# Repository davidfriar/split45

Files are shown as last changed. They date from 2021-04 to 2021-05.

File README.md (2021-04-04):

# The Split Forty Five

A small mechanical keyboard for those who cannot decide if they are ancient or modern.

* "Traditional" row-staggered layout
* Split for better ergonomics
* Based on the Nice!Nano controller for very low power consumption
* Uses Bluetooth Low Energy (BLE) both to connect each half and to connect to the computer

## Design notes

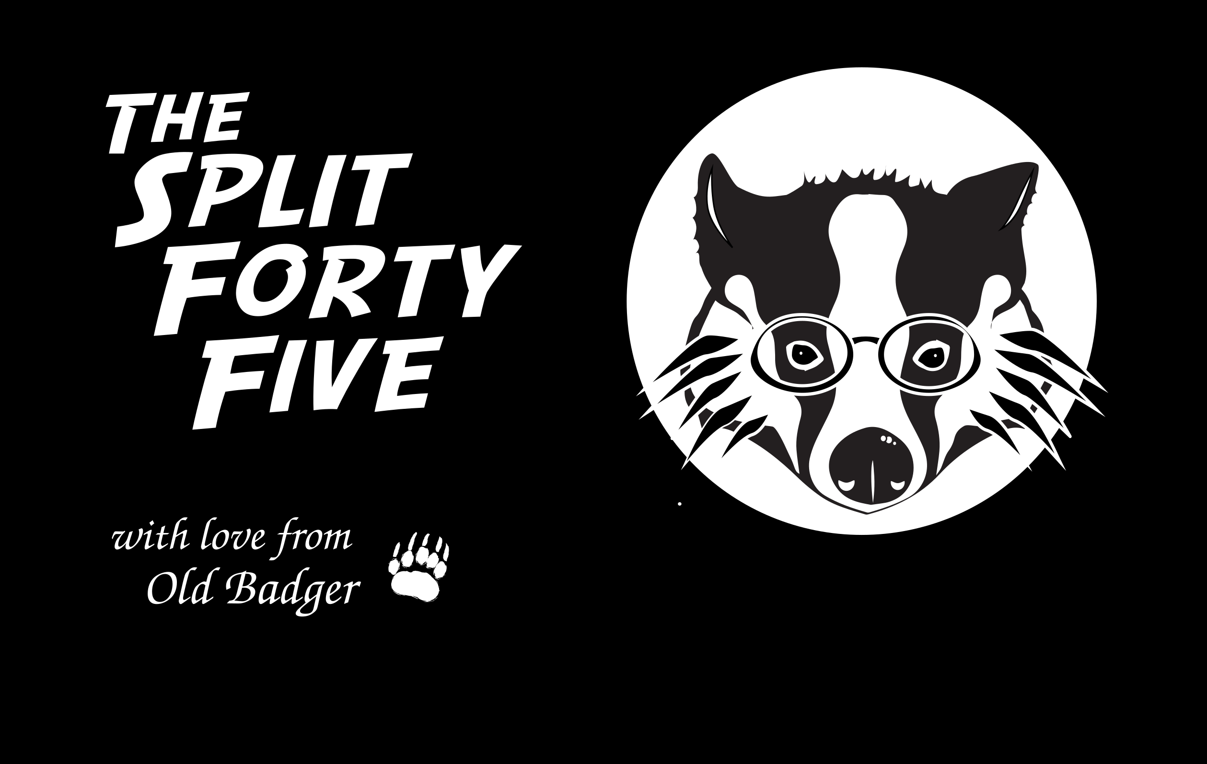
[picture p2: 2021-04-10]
art/bottom.png

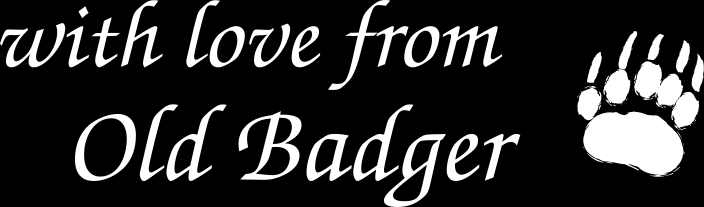
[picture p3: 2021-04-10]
art/withlove.png

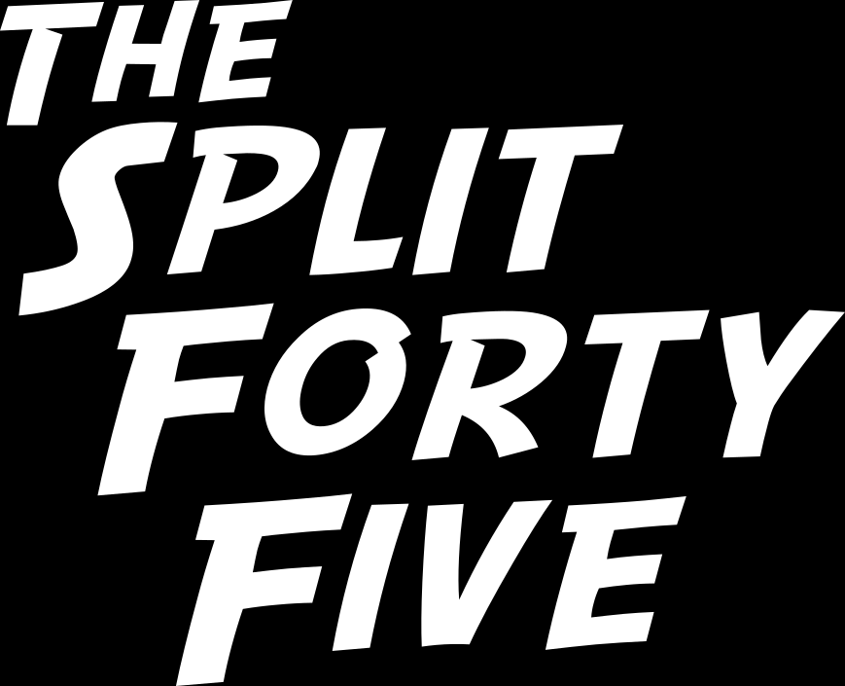
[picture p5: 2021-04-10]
art/split45.png

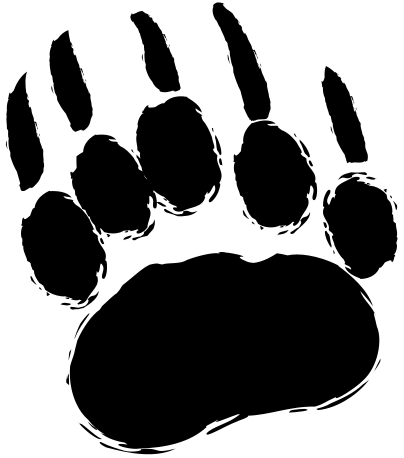
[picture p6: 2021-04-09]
art/rightpaw.png

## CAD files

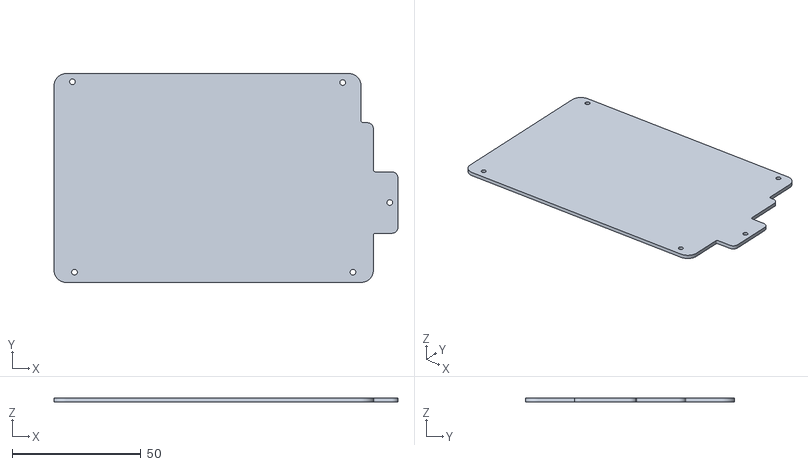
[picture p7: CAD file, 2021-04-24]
case/pcbmodels/split45leftbase.stl
133.4 x 81.0 x 1.60

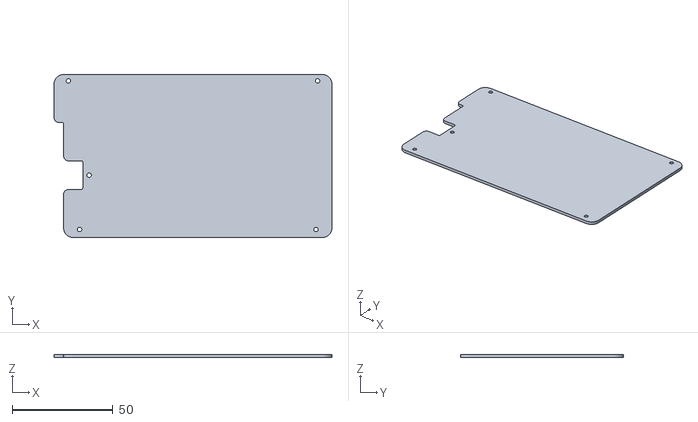
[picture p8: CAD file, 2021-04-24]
case/pcbmodels/split45rightbase.stl
138.1 x 81.0 x 1.60

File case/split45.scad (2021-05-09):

include <BOSL/constants.scad>
use <BOSL/transforms.scad>
include <pcbmodels/holes.scad>
include <pcbmodels/dimensions.scad>
include <pcbmodels/corners.scad>
$fn = 360;
$fs = 1;

show_left=true;
show_right=true;
show_base=true;
show_pcb=true;

wall_thickness=8;
interior_corner_radius=3;
min_height=5;
tilt=6; // [0:0.5:15]
tent=8; // [0:45]
socket_height=4.95;
hole_diameter=3.2;
hole_depth=4.25;
clearance_hole_depth=2;
clearance_hole_offset=1.5;
switch_clearance_hole_offset=11;
stab_clearance_hole_offset=2;
nano_length=33.3;
nano_width=18.1;
nano_thickness=1.6;
nano_clearance=1;
usb_socket_length=8.9;
usb_plug_width=8.9;
usb_plug_height=3.2;
usb_plug_length=8.54;
usb_sheath_offset=2;
usb_sheath_width=usb_plug_width+2*usb_sheath_offset;
usb_sheath_height=usb_plug_height+2*usb_sheath_offset;
usb_sheath_length=30;

/* all(); */
pack();
/* clearance_holes(true); */
/* stab_clearance_holes(true); */
/* switch_clearance_holes(true); */
/* nice_nano_cutout(); */
/* usb_cutout(); */

/* name(); */
/*
to do:


all function
explode
bottom holes
top holes
pcb clearance
right interior
name
pcb / usb cutout
check weird alignment error with nano holes
battery holder
info panel (including clearance height for nano)

pack for printing
*/

module pack() {
  right(5) xrot(180){
    body(true);
    up(40) xrot(180) back(dimensions(false).y) body(false);
  }
}


module all(){
  if(show_left) {
    base(true) body(true) pcb(true) ;
  }
  if(show_right) {
    if(show_left) {
      xmove(left_size.x *1.25)
        base(false) body(false) pcb(false) ;
    }
    else{
      base(false) body(false) pcb(false) ;
    }
  }
}

module body(l=true){
  color("grey")
    difference(){
      body3d(l);
      down(0.1) scale([1,1, 1.1]) body3d(l, interior=true);
      bottom_holes(l);
      tilt_and_tent(l) top_holes(l);
      tilt_and_tent(l) switch_clearance_holes(l);
      tilt_and_tent(l) stab_clearance_holes(l);
      tilt_and_tent(l) name(l);
      align_nano(l, false) down(0.1) scale([1,1, 1.1]) nice_nano_cutout(l);
      tilt_and_tent(l) align_nano(l) translate([-(nano_clearance+1.5), nano_width/2, usb_plug_height/2]) usb_cutout();
    }

  tilt_and_tent(l) children();
}

module body3d(l=true, interior=false){
  for(part = corners(l)) {
    body_part(part, l, interior);
  }
  for(f=fillets(l)){
    fillet(f, l, interior);
  }

}

module body_part(corners, l=true, interior=false) {
  hull() {
    to3d() body_part_2d(corners, l, interior);
    tilt_and_tent(l) to3d() body_part_2d(corners, l, interior);
  }
}




module body_part_2d(corners, l=true, interior=false) {
  offset_interior(interior){
    hull(){
      for(corner = corners) {
        translate([corner.x, corner.y, 0]) circle(corner.z);
      }
    }
  }
}

module offset_interior(interior=false){
  if(interior){
    offset(r=interior_corner_radius)offset(r=-(wall_thickness+interior_corner_radius))  children();
  }
  else {
    children();
  }
}

module to3d(){
  for(i = [0:$children-1]){
    linear_extrude(height=0.0001) children(i);
  }
}

module fillet(f, l=true, interior=false){
  difference(){
    hull(){
      to3d() fillet_2d(f, interior);
      tilt_and_tent(l) to3d() fillet_2d(f, interior);
    }

    down(0.001) scale([1,1, 1.001]){
      hull(){
        to3d() fillet_mask_2d(f, interior);
        tilt_and_tent(l) to3d() fillet_mask_2d(f, interior);
      }
    }
  }
}

module fillet_2d(f, interior=false) {
  fillet_offset(f, interior) translate([f.x, f.y, 0]) flip(f[4], f[3]) square(f.z);
}

module fillet_offset(f, interior){
  if(interior){
    translate([f[4]?-wall_thickness:wall_thickness, f[3]?-wall_thickness:wall_thickness, 0]) children();
  }
  else{
    children();
  }
}
module flip(x, y) {
  if(x){
    if(y) {
      xflip() yflip() children();
    }
    else {
      xflip() children();
    }
  }
  else{
    if(y){
      yflip() children();
    }
    else {
      children();
    }
  }
}

module fillet_mask_2d(f, interior) {
  fillet_offset(f, interior) translate([f.x, f.y, 0]) circle(f.z);
}

module bottom_holes(l=true){
  for(hole = base_holes(l)){
    translate([hole.x, hole.y, -1]) cylinder(d=hole_diameter, h=hole_depth+1);
  }
}


module top_holes(l=true){
  for(hole = holes(l) ){
    if (hole[3]=="T2"){
      translate([hole.x, hole.y, -hole_depth]) cylinder(d=hole_diameter, h=hole_depth+1);
    }
  }
}

module clearance_holes(l=true) {
  for(hole = holes(l)){
    if (hole[3]!="T2"){
      translate([hole.x, hole.y, -clearance_hole_depth]) cylinder(d=hole.z+clearance_hole_offset, h=clearance_hole_depth+1);

    }
  }
  for(hole = plated_holes(l)){
    translate([hole.x, hole.y, -clearance_hole_depth]) cylinder(d=hole.z+clearance_hole_offset, h=clearance_hole_depth+1);
  }

}

module switch_clearance_holes(l=true){
  for(hole=switch_holes(l)) {
    color("blue") translate([hole.x, hole.y, -clearance_hole_depth]) cylinder(d=hole.z+switch_clearance_hole_offset, h=clearance_hole_depth+1);
  }
}

module stab_clearance_holes(l=true){
  for(hole=stab_holes(l)) {
    color("red") translate([hole.x, hole.y, -clearance_hole_depth]) cylinder(d=hole.z+stab_clearance_hole_offset, h=clearance_hole_depth+1);
  }
}

module tilt_and_tent(l=true) {
  /* translate([0,0, min_height + (tan(tent)*dimensions(l).x * 0.5)+(tan(tilt)*dimensions(l).y * 0.5)]) */
  zmove(min_height)
    ymove(-dimensions(l).y) xmove(l?0:right_size.x) yrot(tent_angle(l)) xrot(tilt) xmove(l?0:-right_size.x) ymove(dimensions(l).y)
    children();
}

function dimensions(l) = l ? left_size : right_size ;

function base_holes(l) = l ? left_base_holes : right_base_holes ;

function holes(l) = l ? left_holes : right_holes ;

function plated_holes(l) = l ? left_plated_holes : right_plated_holes ;

function tent_angle(l) = l ? -tent : tent ;

function corners(l) = l ? left_corners : right_corners;

function fillets(l) = l ?  left_fillets : right_fillets ;

function switch_holes(l) = [ for( hole = holes(l)) if (hole[3] == "T4" && hole.y > -70) hole ];

function stab_holes(l) = [ for( hole = holes(l)) if (hole[3] == "T3" || (hole[3] == "T4" && hole.y < -70)) hole ];

module pcb(l=true){
  if(show_pcb){
    color("red")up(dimensions(l).z)  {
      if (l) {
        pcb_left();
      }
      else {
        pcb_right();
      }
    }
    //translate([0,0,-(1.6+socket_height)]) nice_nano();
    align_nano(l) nice_nano();
  }
}

module centered(l=true) {
  translate([-dimensions(l).x/2, dimensions(l).y/2, 0]) children();
}

module base(l=true){
  if(show_base){
    color("red")up(dimensions(l).z)  {
      if (l) {
        base_left();
      }
      else {
        base_right();
      }
    }
  }
  up(dimensions(l).z) children();
}

module pcb_left() {
  import("pcbmodels/split45left.stl");
}

module pcb_right() {
  import("pcbmodels/split45right.stl");
}

module base_left() {
  import("pcbmodels/split45leftbase.stl");
}

module base_right() {
  import("pcbmodels/split45rightbase.stl");
}

module nice_nano() {
  nano_socket_border = (nano_width - 2.54*7) / 2 ;
  color("dimgray") rounded_rect([nano_length, nano_width, nano_thickness], radius=1.5);
  translate([ 0, (nano_width - usb_socket_length)/2 , 0 ]) rotate([90,0,90]) usb_socket();
  for(i=[0:1]){
    translate([2.82,nano_socket_border+i*6*2.54,nano_thickness]) socket();
  }
}


module nice_nano_cutout(left=true){

  translate([-nano_clearance, -nano_clearance]) hull(){
    rounded_rect([nano_length + 2*nano_clearance, nano_width+2*nano_clearance, 0.001], 1.5);
    tilt_and_tent(left) rounded_rect([nano_length + 2*nano_clearance, nano_width+2*nano_clearance, 0.001], 1.5);
  }
}


module rounded_rect(size, radius=5){
  hull(){
    translate([radius, radius]) cylinder(h=size.z, r=radius);
    translate([size.x-radius, radius]) cylinder(h=size.z, r=radius);
    translate([radius, size.y-radius]) cylinder(h=size.z, r=radius);
    translate([size.x-radius, size.y-radius]) cylinder(h=size.z, r=radius);
  }
}


module usb_socket(){
  color("silver") rounded_rect([8.9, 3.2, 6.5],radius=1);
}

module usb_cutout(){
  translate([0, -usb_sheath_width/2, -usb_sheath_height/2]) zrot(90)xrot(90) {
    translate([usb_sheath_offset, usb_sheath_offset, 0]) rounded_rect([usb_plug_width, usb_plug_height, usb_plug_length],radius=1);
    translate([0,0, -usb_sheath_length]) rounded_rect([usb_sheath_width, usb_sheath_height, usb_sheath_length],radius=3);
  }


}

module socket() {
  difference(){
    color("black") cube([30.48, 2.54, socket_height]);
    for(i=[0:11]){
      translate([1.27+i*2.54, 1.27, -1 ]) cylinder(d=1.092,h=10);
    }
  }
}


module align_nano(l=true, align_z=true){
  offsetX = l ? 3.3715 : 102.712+33.3-1.27;
  offsetY = l ? -40: -21.747;    // to do: was expecting left offset to be 40.147 - where is this error coming from?
  offsetZ = align_z ? -(1.6+socket_height) : 0 ;
  rotZ = l ? 0 : 180;
  translate([offsetX,offsetY,offsetZ ]) zrot(rotZ) children();
}
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

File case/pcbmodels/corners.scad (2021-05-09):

left_corners = [
  [
    [4.7625, -4.7625, 4.7625 ],
    [114.3, -4.7625, 4.7625 ],
    [4.7625, -76.2, 4.7625 ],
    [114.3, -76.2, 4.7625 ],
  ],
  [
    [4.7625, -76.2, 4.7625 ],
    [119.062, -76.2, 4.7625 ],
    [121.444, -21.4312, 2.38125 ],
    [4.7625, -21.4312, 2.38125 ]
  ],
  [
    [130.969, -59.5312, 2.38125 ],
    [130.969, -40.4812, 2.38125 ],
    [4.7625, -59.5312, 2.38125 ],
    [4.7625, -40.4812, 2.38125 ],
  ]
];



left_fillets = [
  [124.619, -62.7063, 0.79375, false , true],
  [124.619, -37.3062, 0.79375, true , true],
  [119.856, -18.2563, 0.79375, true , true]
];


right_corners = [
  [
    [133.35, -76.2, 4.7625 ],
    [133.35, -4.7625, 4.7625 ],
    [19.05005, -76.2, 4.7625 ],
    [19.05005, -4.7625, 4.7625 ],
  ],
  [
    [9.525, -76.2, 4.7625 ],
    [133.35, -76.2, 4.7625 ],
    [7.14375, -59.5312, 2.38125 ],
    [133.35, -59.5312, 2.38125 ],
  ],
  [
    [7.14375, -40.4812, 2.38125 ],
    [7.14375, -2.38125, 2.38125 ],
    [135.73125, -40.4812, 2.38125 ],
    [133.35, -4.7625, 4.7625 ],
  ],
  [
    [4.7625, -4.7625, 4.7625 ],
    [133.35, -4.7625, 4.7625 ],
    [2.38125, -21.4312, 2.38125 ],
    [133.35, -21.4312, 2.38125 ],
  ]
  ];

right_fillets = [
  [3.96875, -24.6062, 0.79375, false, false ],
  [13.4938, -43.6562, 0.79375, false, false ],
  [13.4938, -56.3562, 0.79375, true, false ],
];

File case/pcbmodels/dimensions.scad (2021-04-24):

left_size = [133.35, 80.9625, 1.6];
right_size = [138.113, 80.9625, 1.6];

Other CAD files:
case/pcbmodels/holes.scad

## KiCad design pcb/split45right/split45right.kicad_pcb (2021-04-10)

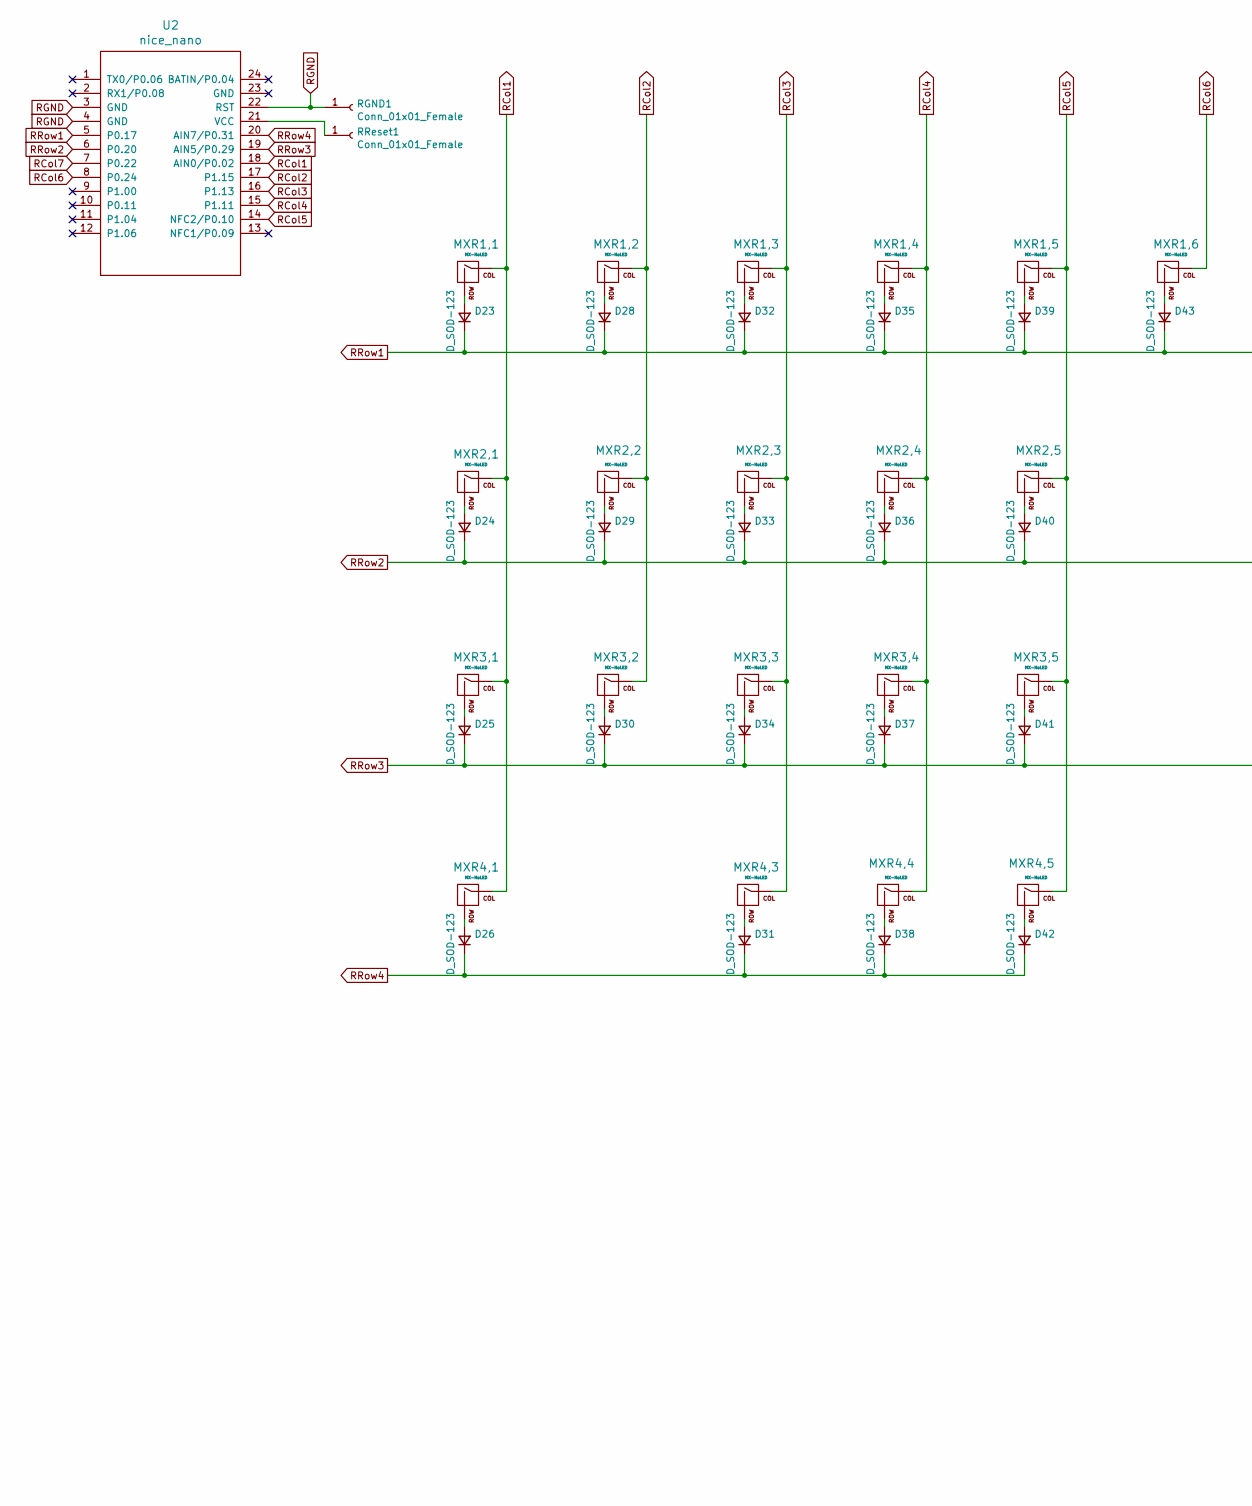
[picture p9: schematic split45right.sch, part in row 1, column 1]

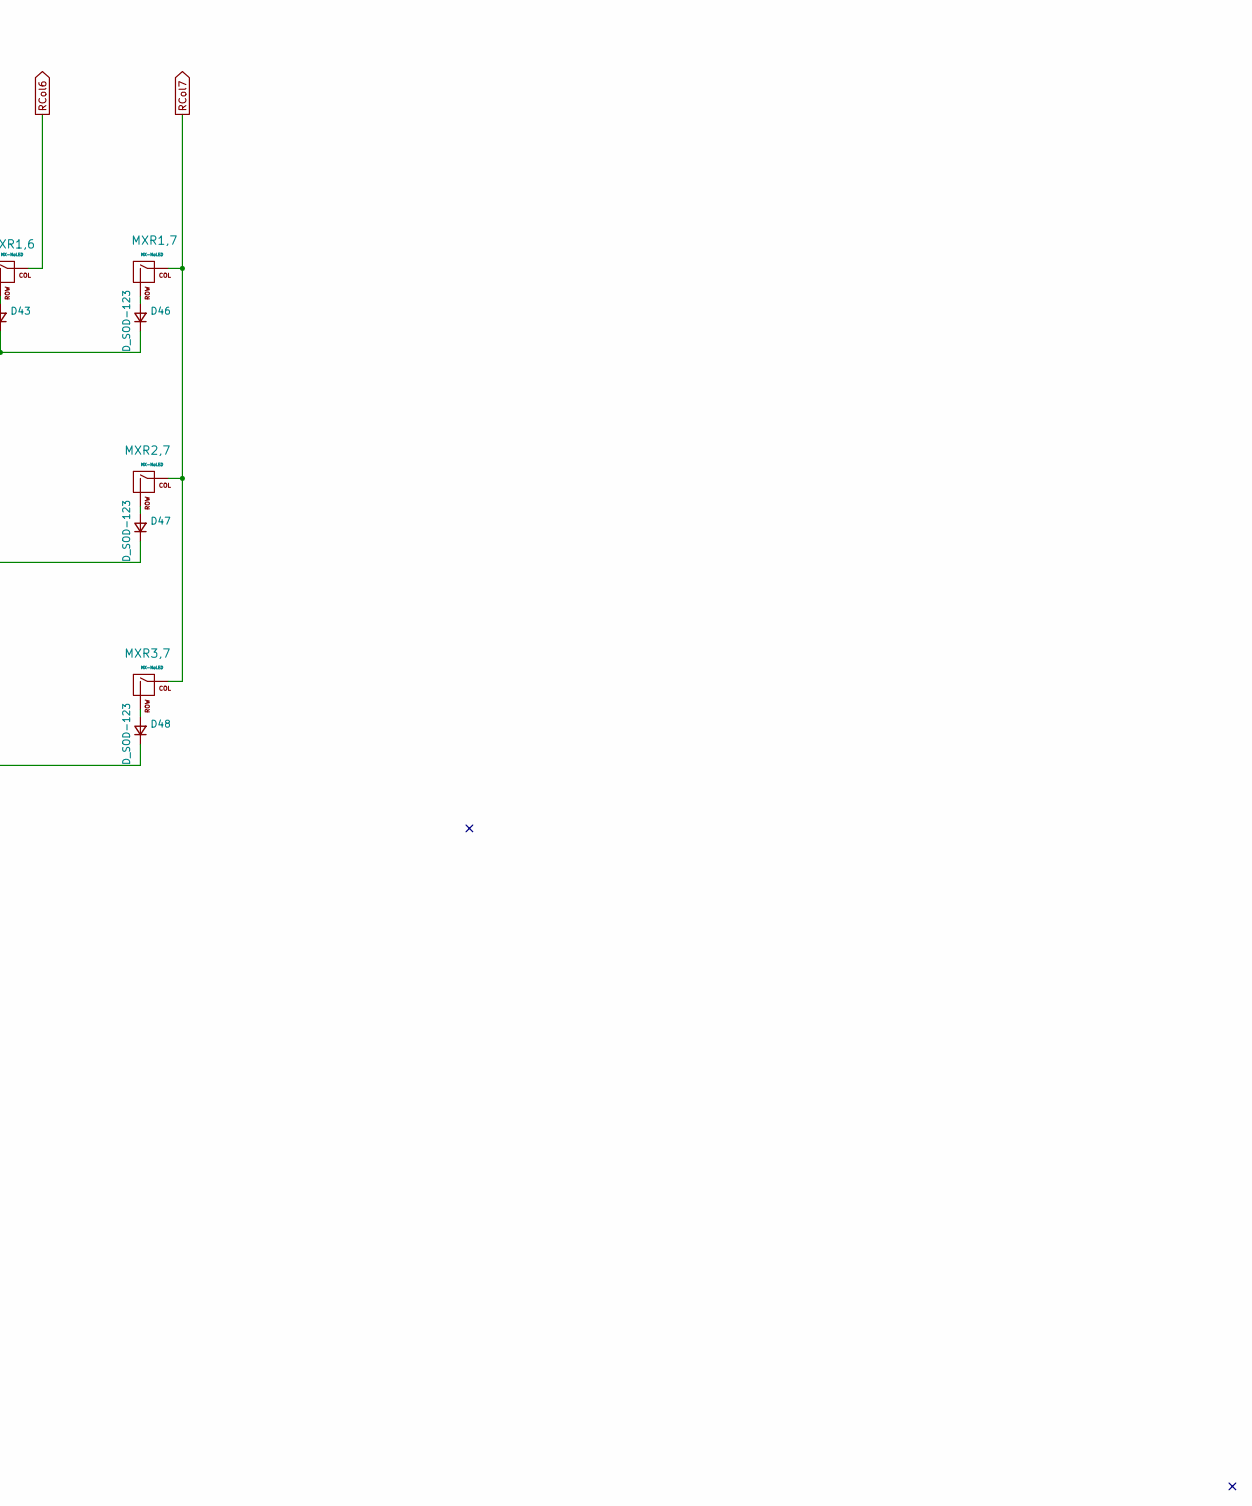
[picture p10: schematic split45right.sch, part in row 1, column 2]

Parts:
D23, D24, D25, D26, D28, D29, D30, D31, D32, D33, D34, D35, D36, D37, D38, D39, D40, D41, D42, D43, D46, D47, D48: D_SOD-123
MXR1,1, MXR1,2, MXR1,3, MXR1,4, MXR1,5, MXR1,6, MXR1,7, MXR2,1, MXR2,2, MXR2,3, MXR2,4, MXR2,5, MXR3,1, MXR3,2, MXR3,3, MXR3,4, MXR3,5, MXR4,3, MXR4,5: MX-NoLED; MXOnly-1U-NoLED
MXR2,7: MX-NoLED; MXOnly-1.75U-NoLED
MXR3,7, MXR4,4: MX-NoLED; MXOnly-1.25U-NoLED
MXR4,1: MX-NoLED; MXOnly-2.75U-NoLED
RGND1: Conn_01x01_Female; SolderWire-0.15sqmm_1x01_D0.5mm_OD1.5mm
RReset1: Conn_01x01_Female; SolderWire-0.15sqmm_1x01_D0.5mm_OD1.5mm
U2: nice_nano

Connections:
unnamed: D23.2 (A), MXR1,1.2 (ROW)
unnamed: D24.2 (A), MXR2,1.2 (ROW)
unnamed: D25.2 (A), MXR3,1.2 (ROW)
unnamed: D26.2 (A), MXR4,1.2 (ROW)
unnamed: D28.2 (A), MXR1,2.2 (ROW)
unnamed: D29.2 (A), MXR2,2.2 (ROW)
unnamed: D30.2 (A), MXR3,2.2 (ROW)
unnamed: D31.2 (A), MXR4,3.2 (ROW)
unnamed: D32.2 (A), MXR1,3.2 (ROW)
unnamed: D33.2 (A), MXR2,3.2 (ROW)
unnamed: D34.2 (A), MXR3,3.2 (ROW)
unnamed: D35.2 (A), MXR1,4.2 (ROW)
unnamed: D36.2 (A), MXR2,4.2 (ROW)
unnamed: D37.2 (A), MXR3,4.2 (ROW)
unnamed: D38.2 (A), MXR4,4.2 (ROW)
unnamed: D39.2 (A), MXR1,5.2 (ROW)
unnamed: D40.2 (A), MXR2,5.2 (ROW)
unnamed: D41.2 (A), MXR3,5.2 (ROW)
unnamed: D42.2 (A), MXR4,5.2 (ROW)
unnamed: D43.2 (A), MXR1,6.2 (ROW)
unnamed: D46.2 (A), MXR1,7.2 (ROW)
unnamed: D47.2 (A), MXR2,7.2 (ROW)
unnamed: D48.2 (A), MXR3,7.2 (ROW)
unnamed: RReset1.1, U2.21 (VCC)
RCol1: MXR1,1.1 (COL), MXR2,1.1 (COL), MXR3,1.1 (COL), MXR4,1.1 (COL), U2.18 (AIN0/P0.02)
RCol2: MXR1,2.1 (COL), MXR2,2.1 (COL), MXR3,2.1 (COL), U2.17 (P1.15)
RCol3: MXR1,3.1 (COL), MXR2,3.1 (COL), MXR3,3.1 (COL), MXR4,3.1 (COL), U2.16 (P1.13)
RCol4: MXR1,4.1 (COL), MXR2,4.1 (COL), MXR3,4.1 (COL), MXR4,4.1 (COL), U2.15 (P1.11)
RCol5: MXR1,5.1 (COL), MXR2,5.1 (COL), MXR3,5.1 (COL), MXR4,5.1 (COL), U2.14 (NFC2/P0.10)
RCol6: MXR1,6.1 (COL), U2.8 (P0.24)
RCol7: MXR1,7.1 (COL), MXR2,7.1 (COL), MXR3,7.1 (COL), U2.7 (P0.22)
RGND: RGND1.1, U2.3 (GND), U2.4 (GND), U2.22 (RST)
RRow1: D23.1 (K), D28.1 (K), D32.1 (K), D35.1 (K), D39.1 (K), D43.1 (K), D46.1 (K), U2.5 (P0.17)
RRow2: D24.1 (K), D29.1 (K), D33.1 (K), D36.1 (K), D40.1 (K), D47.1 (K), U2.6 (P0.20)
RRow3: D25.1 (K), D30.1 (K), D34.1 (K), D37.1 (K), D41.1 (K), D48.1 (K), U2.19 (AIN5/P0.29)
RRow4: D26.1 (K), D31.1 (K), D38.1 (K), D42.1 (K), U2.20 (AIN7/P0.31)

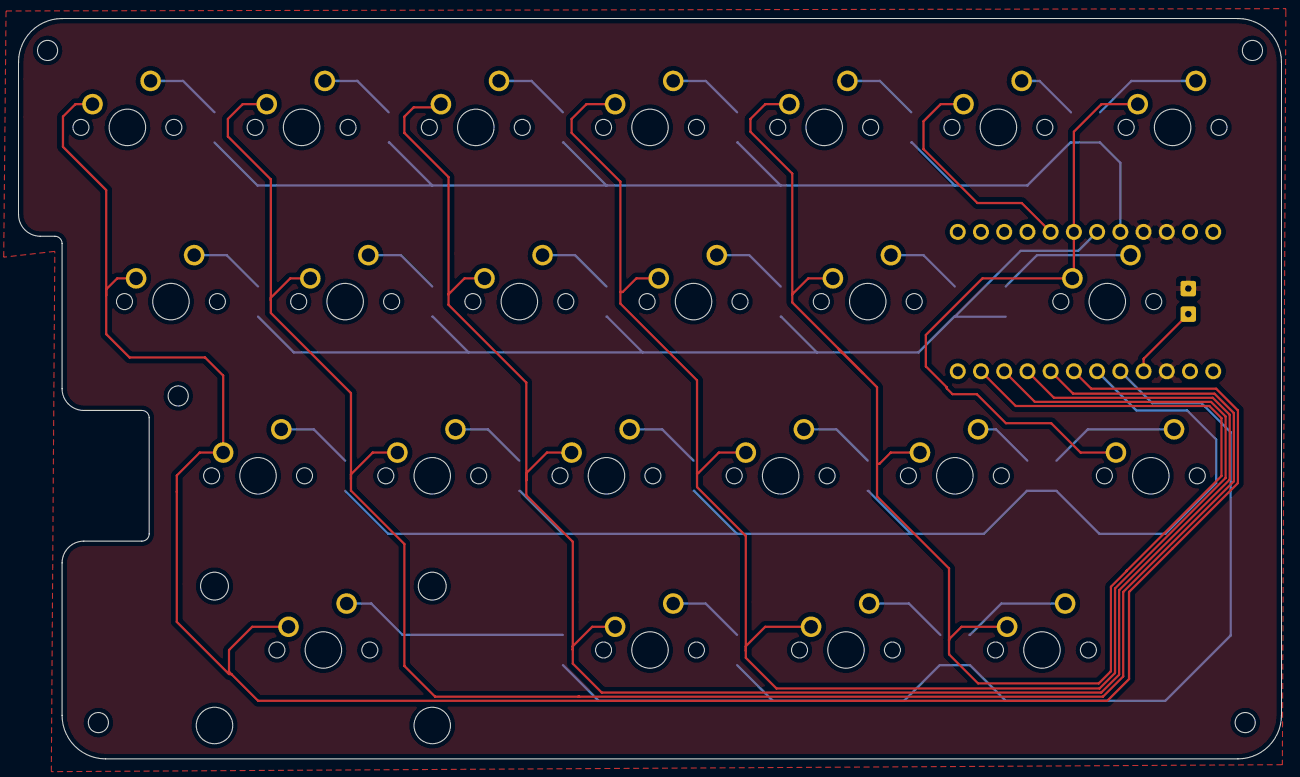
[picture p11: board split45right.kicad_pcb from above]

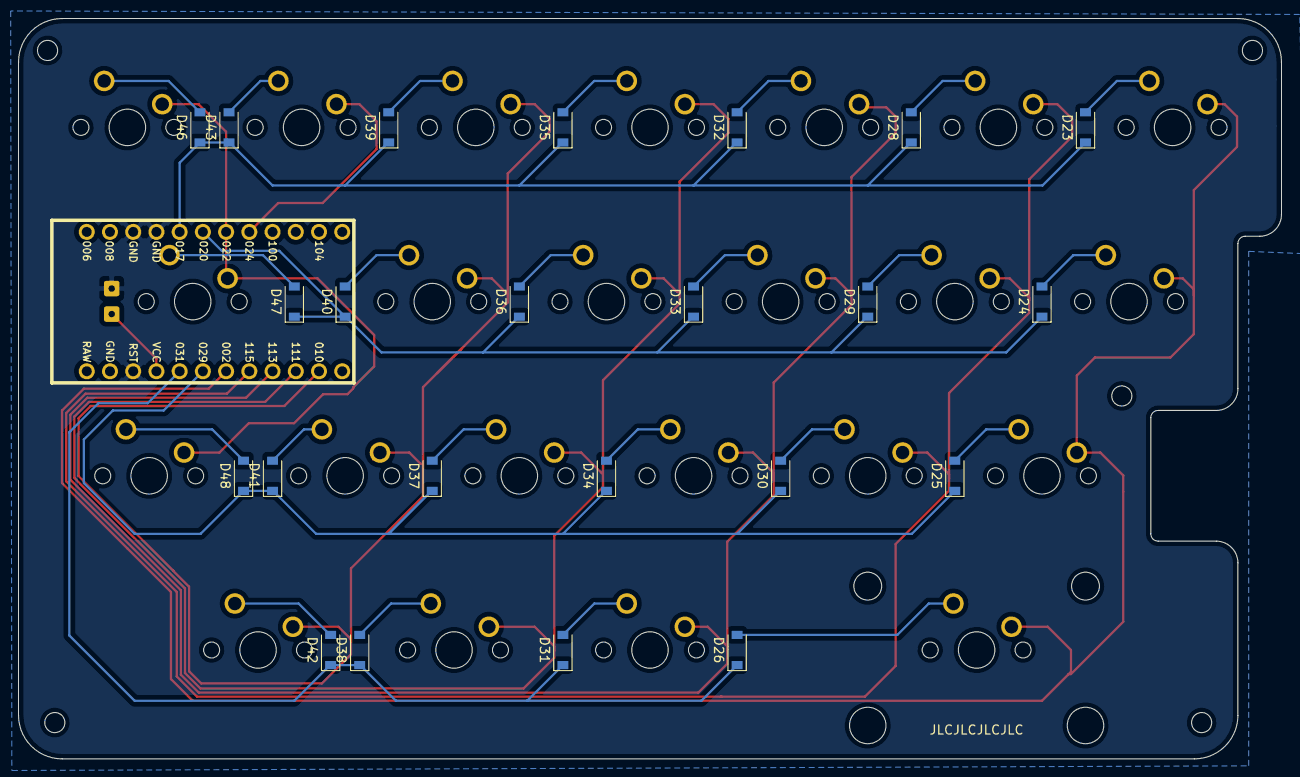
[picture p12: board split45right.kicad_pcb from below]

Board: 2 copper layers, 138.1 x 81.0 mm, 49 parts (23 on the bottom side), 36 nets.

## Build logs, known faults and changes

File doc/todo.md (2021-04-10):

- [ ] hardware
  - [ ] solder battery and test ble
- [ ] case
  - [ ] start design
- [ ] firmware
   - [ ] space cadet parens
   - [ ] move to config-only repo
- [ ] pcb
  - [x] move screw holes
  - [x] change corner radii
  - [x] design for back
  - [ ] test whether copper on base affects bluetooth
  - [x] generate gerbers
  - [x] order
- [ ] other
  - [ ] order switches

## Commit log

2021-04-04 Add kicad project
    [split45.kicad_pcb, split45.sch]
2021-04-04 add schema, pcb, place components
    [split45.kicad_pcb, split45.sch]
2021-04-05 route the left side
    [split45.kicad_pcb, split45.sch]
2021-04-05 right hand routing and fill areas
    [split45.kicad_pcb, split45.sch]
2021-04-05 add reset pads
    [split45.kicad_pcb, split45.sch]
2021-04-09 move holes in base, add images and text to pcb
    [split45.kicad_pcb]
2021-04-09 add nice-nano-kicad files
2021-04-09 tweak position of boards on page
    [split45.kicad_pcb]
2021-04-09 split pcbs into separate projects
    [split45.kicad_pcb, split45.sch, split45left.kicad_pcb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]
2021-04-10 add gerbers dir to .gitignore
2021-04-10 final changes for version 0.1
    [split45left.kicad_pcb, split45leftbase.kicad_pcb, split45right.kicad_pcb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]
2021-04-10 update todo
    [split45.scad, split45left-old.stl]
2021-04-24 tiltable case
    [corners.scad, dimensions.scad, holes.scad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]
2021-05-05 case changes
    [corners.scad, split45.scad]
2021-05-09 finish the case
    [corners.scad, split45.scad]
2021-05-09 release case v0.1
